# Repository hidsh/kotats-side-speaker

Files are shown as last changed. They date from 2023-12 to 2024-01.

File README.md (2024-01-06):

# こたつサイドなタワースピーカー

お一人様用こたつで快適ライフを送るため、3Dプリンタでニアフィールド向けのスピーカーを作っています。

- [塩ビパイプとダイソー330円スピーカーでつくるバックロードホーン共鳴管](VU50-stand-daiso330)
- [塩ビパイプとNFJの470円スピーカーでつくるバスレフ管](VU75-stand-nfj-470)

元々は、帰郷したときに祖母がテレビを大音量で観ていたのを見て、なにか出来ないかと考えたのが始まりでした。

しかし、コロナ禍のうちにその祖母も他界してしまい、結局作ったものは渡せずじまいになりました。

せっかく始めたことなので、今は日本のこたつ文化とチープオーディオの融合を目的としています。

寒い冬はこたつでまったり音楽を聴いたり、映画を観たりするのもまた乙なものですね。

# link

- [MXA08 - PAM8408 Mini Amplifier with Cherry MX Compatible Mechanical Switches](https://github.com/hidsh/MXA08)

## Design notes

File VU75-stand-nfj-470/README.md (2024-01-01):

# 塩ビパイプとNFJの470円スピーカーでつくるバスレフ管

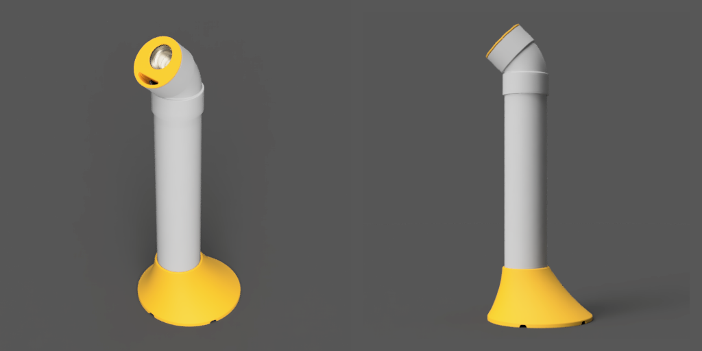
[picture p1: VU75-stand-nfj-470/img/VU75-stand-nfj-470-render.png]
render


ホームセンターで売っている塩ビパイプとアマゾンで470円（送料別）で売っているNFJのスピーカーでタワー型のスピーカーを作りました。

ユニットが重いので、太いパイプを使いました。また、耳に近づけられるように偏芯した配置になっています。

箱容積が大きいせいか、余裕のあるバランスのいい音になりました。

- パイプ呼び径: 75
- 箱容積: 約2.7L
- 構造: バスレフ
- ポート面積: 約5cm²
- ダクト長: 4cm
- スピーカーの高さ: 575mm

スピーカーの高さは固定です。

## 3Dデータ
|名称|数量|メモ|
|---|:---:|---|
|[ベース](step/VU75-stand-nfj-470-base.step)|2|VUパイプを差し込む土台です|
|[バッフル](step/VU75-stand-nfj-470-buffle.step)|2|スピーカーを固定するパーツです。エルボに差し込みます。|
|[M3t2ワッシャ](step/VU75-stand-nfj-470-washer-m3-t2.step)|8|スピーカーをバッフルにネジ止めするのにネジが長すぎるので、このワッシャにネジを差し込んだ後にスピーカーを止めます。|

## 部品表

| # | 名称 | 数量 | 例 | メモ |
| ---: | --- |:---:| --- | --- |
| 1 | スピーカーユニット | 2 | [NFJ フルレンジスピーカーユニット2インチ(52mm) 4Ω/MAX20W \[スピーカー自作/DIYオーディオ\]/1個](https://www.amazon.co.jp/gp/product/B074MRC7DF)| エージングを50時間ほどしてやると、いい感じになりました。 |
| 2 | VUパイプ 75x0.5m| 2 | [クボタケミックス 排水用塩ビパイプ ＶＵ ７５Ｘ０．５Ｍ](https://www.amazon.co.jp/dp/B08TG9537P)|  |
| 3 | エルボ 75| 2 | [クボタケミックス 排水・通気・雨水立とい用 VU継手 VU-45L 75](https://www.amazon.co.jp/dp/B00I4KQWFK)|  |
| 4 | 端子台 | 2 | [2芯x2本ワンタッチコネクタ](https://www.amazon.co.jp/gp/product/B0C6FBPBZJ)|スピーカーケーブルの中継用|
| 5 | M3 L8 ねじ | 10 | [TRUSCO(トラスコ) ナべ頭小ネジ 三価 白 全ネジ サイズM3×8 240本入 B7010308](https://www.amazon.co.jp/gp/product/B002A5MJXO) | スピーカーをバッフルの内側に止めるのに使用<br>端子台をベースの内側に止めるのに使用 |
| 6 | 2芯ケーブル | 1 | [協和ハーモネット ビニル平形コード/スピーカーコード VFF 0.3SQ 10m 赤/ 黒](https://www.amazon.co.jp/dp/B01HARDAZC) | 0.3sq～0.75sq（AWG22～18）, 約80cm |
| 7 | コードフック | 2 | [コードフックS 粘着テープ式 16個入](https://jp.daisonet.com/products/4549131176919)|エルボの内側でスピーカーケーブルを止めるのに使用|
| 8 | ホットボンド | 適宜 |[グルースティック ２０本入 乳白色](https://jp.daisonet.com/collections/handmade0211/products/4549131300857)| 底面のケーブル穴を塞ぐのに使用 |

## link

- [こたつサイドなタワースピーカー](../README.md)

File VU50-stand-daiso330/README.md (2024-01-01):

# 塩ビパイプとダイソー330円スピーカーでつくるバックロードホーン共鳴管

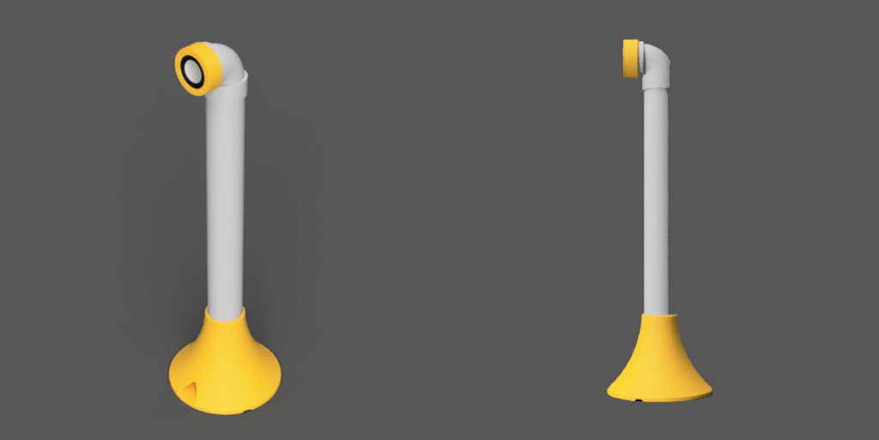
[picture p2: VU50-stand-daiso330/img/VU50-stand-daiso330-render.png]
render


ホームセンターで売っている塩ビパイプとダイソーの330円スピーカーのユニットでタワー型のスピーカーを作りました。

安く作れるわりに、低音が自然な感じで出ます。

- パイプ呼び径: 50
- 箱容積: 約1.3L
- 構造: バックロードホーン
- ポート面積: 約5cm²
- ホーン長: 約65cm
- スピーカーの高さ: 550mm（40mmカラー使用時）

スピーカーの高さはカラーの長さで調整できます。カラーなしでは510mmになります。

## 3Dデータ
|名称|数量|メモ|
|---|:---:|---|
|[ベース](step/VU50-stand-daiso330-base.step)|2|VUパイプを差し込む土台です|
|[バッフルケース](step/VU50-stand-daiso330-buffle-case.step)|2|スピーカーを固定するパーツです。エルボに差し込みます。|
|[バッフルプレート](step/VU50-stand-daiso330-buffle-plate.step)|2|スピーカーの前面カバーです。これとバッフルケースでスピーカーの金具を挟みます。|
|[40mmカラー](step/VU50-stand-daiso330-collar-L40.step)|2|ベースの中のパイプ穴に入れてスピーカーの高さを調整するパーツです。座高が低い人には不要かも。|

## 部品表

| # | 名称 | 数量 | 例 | メモ |
| ---: | --- |:---:| --- | --- |
| 1 | スピーカーユニット | 1 | [ダイソー ミニスピーカー](https://jp.daisonet.com/products/4549131578874) | バラして、スピーカーユニットだけ取り出します |
| 2 | VUパイプ 50x0.5m| 2 | [クボタケミックス 排水用塩ビパイプ ＶＵ ５０Ｘ０．５Ｍ](https://www.amazon.co.jp/gp/product/B08TGCDHS6) |  |
| 3 | エルボ 50| 2 | [クボタケミックス DV継手 エルボ DV-DL 50 DVDL50](https://www.amazon.co.jp/gp/product/B01N9XAYYG) |  |
| 4 | 端子台 | 2 | [2芯x2本ワンタッチコネクタ](https://www.amazon.co.jp/gp/product/B0C6FBPBZJ) |スピーカーケーブルの中継用|
| 5 | M3 L10 ねじ | 2 | [TRUSCO ナべ頭小ネジ 三価 白 全ネジ M3×10 214本入 B701-0310](https://www.amazon.co.jp/gp/product/B002A5MJ3O) |端子台をベースの内側に止めるのに使用|
| 6 | M3 L8 ねじ | 8 | [TRUSCO ナべ頭小ネジ 三価 白 全ネジ サイズM3×8 240本入 B7010308](https://www.amazon.co.jp/gp/product/B002A5MJXO) |スピーカーをバッフルプレートとバッフルケースに止めるために使用|
| 7 | M3 ワッシャ | 8 | [TRUSCO 平ワッシャー ステンレス サイズM3 490個入 B270003](https://www.amazon.co.jp/gp/product/B002A5NHYE) | スピーカーをバッフルプレートとバッフルケースに止めるために使用|
| 8 | 2芯ケーブル | 1 | [協和ハーモネット ビニル平形コード/スピーカーコード VFF 0.3SQ 10m 赤/ 黒](https://www.amazon.co.jp/dp/B01HARDAZC) | 0.3sq～0.75sq（AWG22～18）, 約80cm |
| 9 | コードフック | 2 | [コードフックS 粘着テープ式 16個入](https://jp.daisonet.com/products/4549131176919) | エルボの内側でスピーカーケーブルを止めるのに使用 |
| 10 | ホットボンド | 適宜 |[グルースティック ２０本入 乳白色](https://jp.daisonet.com/collections/handmade0211/products/4549131300857)| 底面のケーブル穴を塞ぐのに使用 |

## link

- [こたつサイドなタワースピーカー](../README.md)

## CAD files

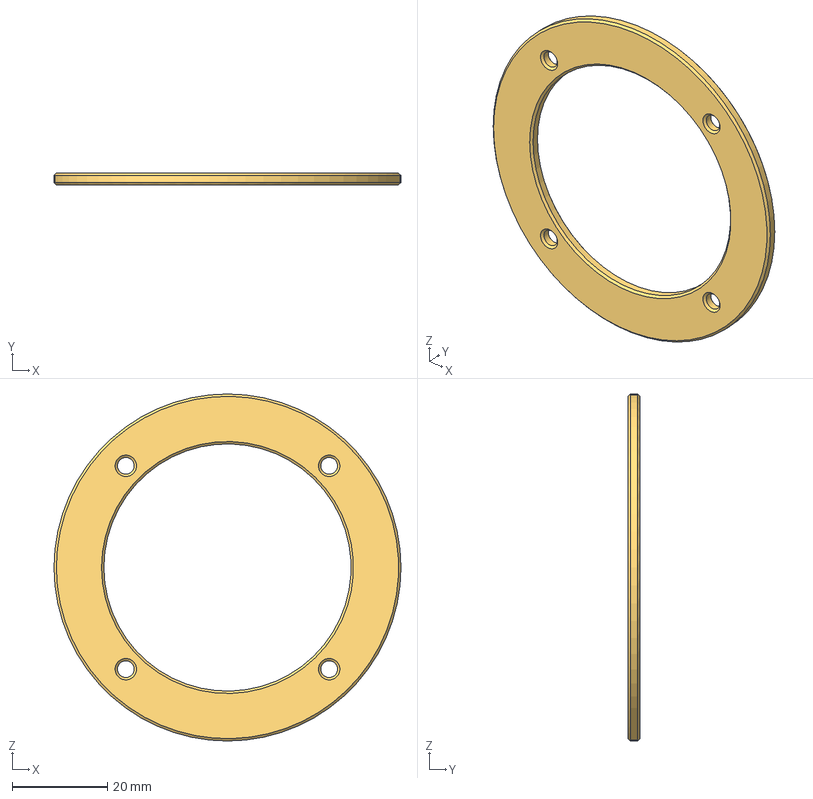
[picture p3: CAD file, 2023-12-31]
VU50-stand-daiso330/step/VU50-stand-daiso330-buffle-plate.step
73.0 x 2.50 x 73.0 mm

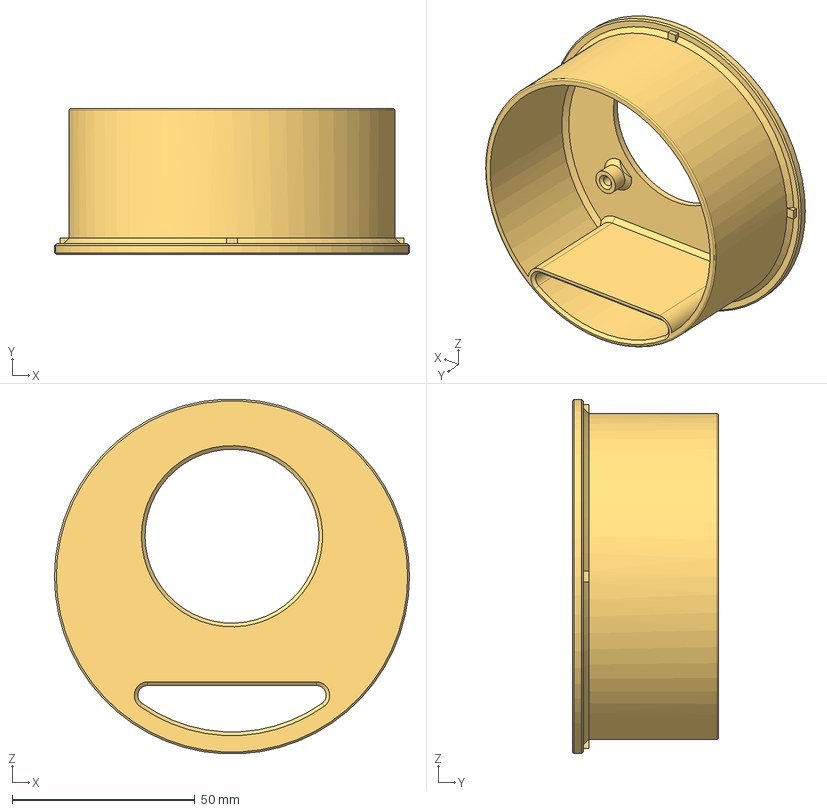
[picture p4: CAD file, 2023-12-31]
VU75-stand-nfj-470/step/VU75-stand-nfj-470-buffle.step
97.0 x 40.0 x 96.9 mm

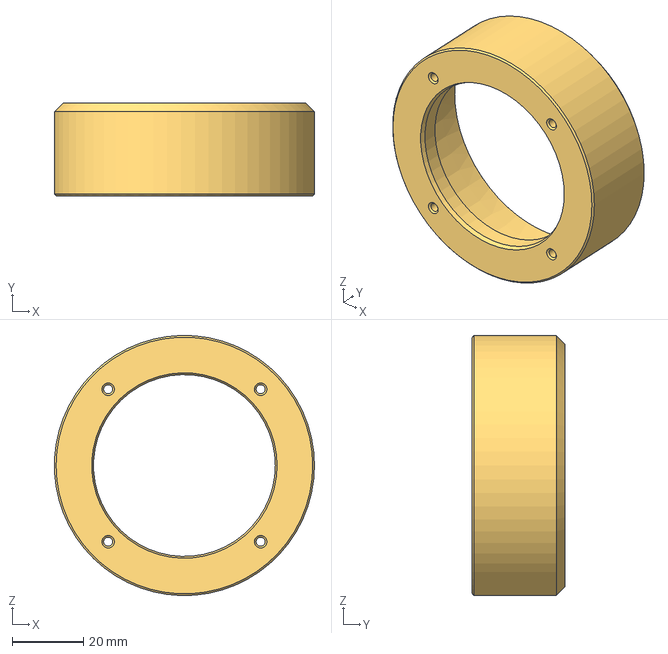
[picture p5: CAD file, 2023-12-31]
VU50-stand-daiso330/step/VU50-stand-daiso330-buffle-case.step
72.9 x 26.0 x 73.0 mm

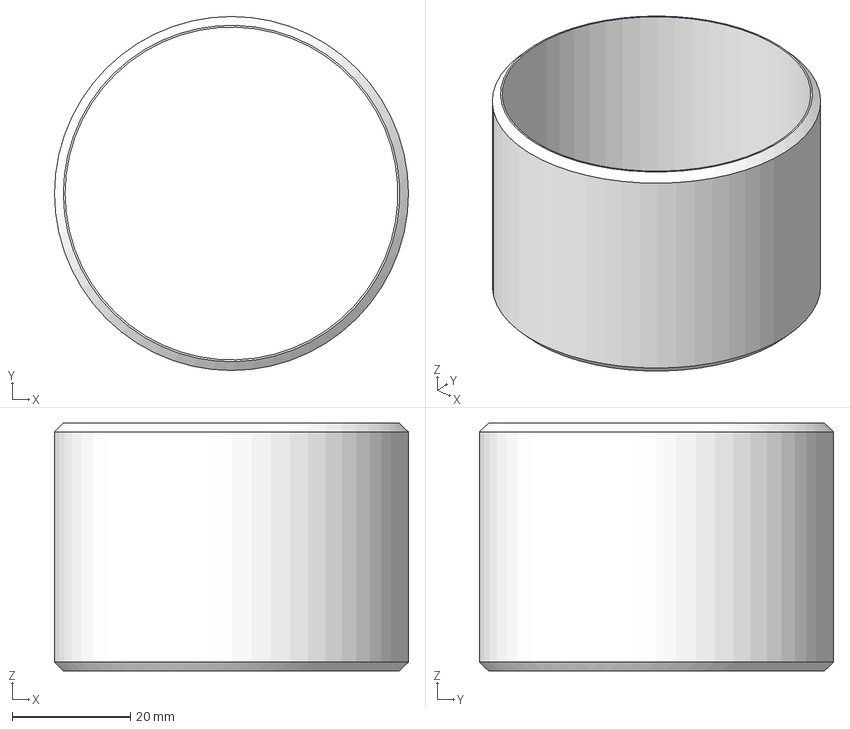
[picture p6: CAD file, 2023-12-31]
VU50-stand-daiso330/step/VU50-stand-daiso330-collar-L40.step
60.0 x 60.0 x 42.0 mm

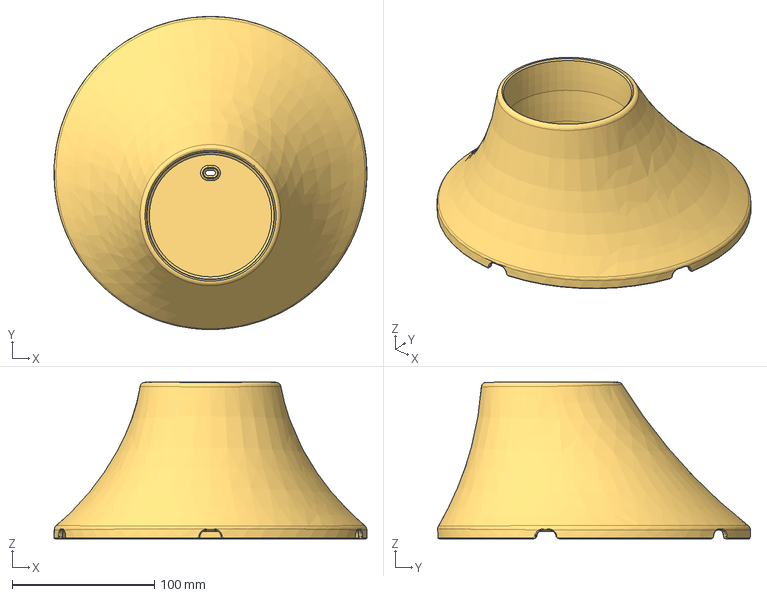
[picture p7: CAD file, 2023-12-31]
VU75-stand-nfj-470/step/VU75-stand-nfj-470-base.step
220.0 x 220.0 x 110.0 mm

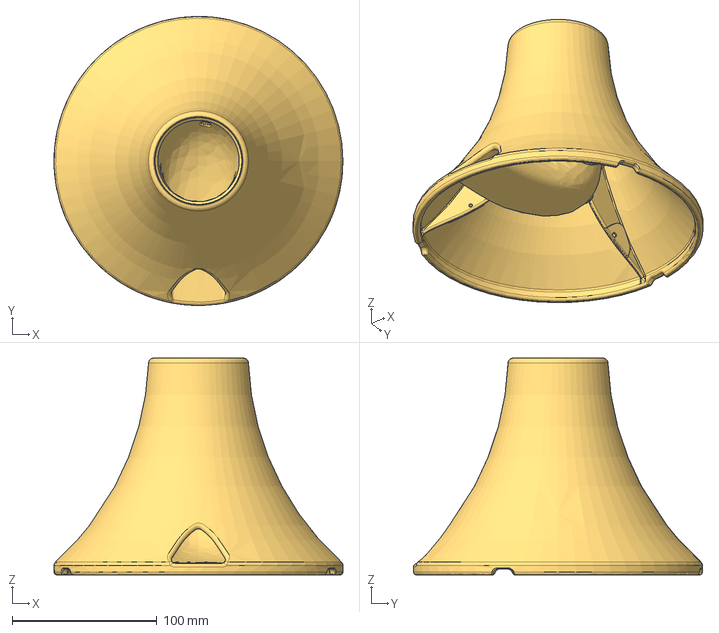
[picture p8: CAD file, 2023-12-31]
VU50-stand-daiso330/step/VU50-stand-daiso330-base.step
199.9 x 200.0 x 150.0 mm

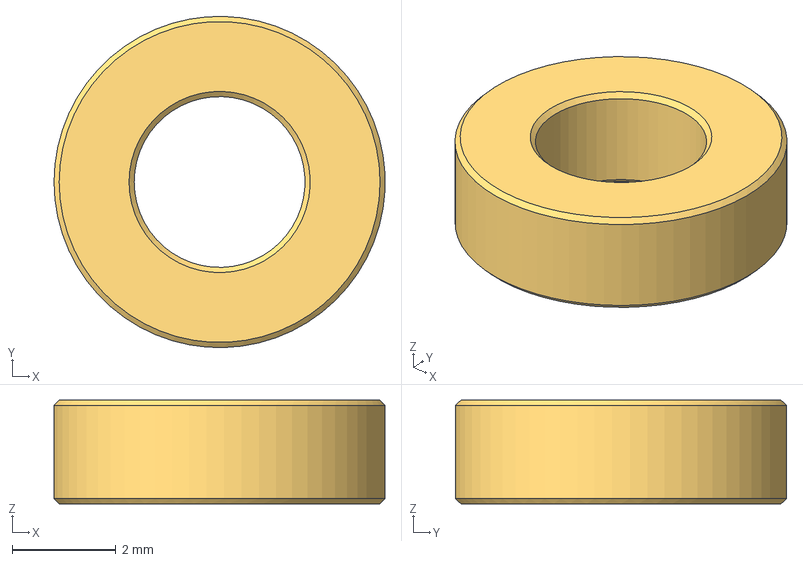
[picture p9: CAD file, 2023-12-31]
VU75-stand-nfj-470/step/VU75-stand-nfj-470-washer-m3-t2.step
6.40 x 6.40 x 2.00 mm
